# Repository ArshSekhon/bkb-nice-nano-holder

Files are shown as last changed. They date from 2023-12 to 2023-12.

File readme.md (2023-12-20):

## Holder PCB for nice!nano

### nice!nano v2 holder PCB for Bastard Keyboards Charybdis
### WARNING: The PCBs have been validated, they are confirmed to be working, but small changes have been made since the original batch was ordered; there might be discrepancies between the schematic and PCB, use at your own risk and go over the files before ordering any prototypes.

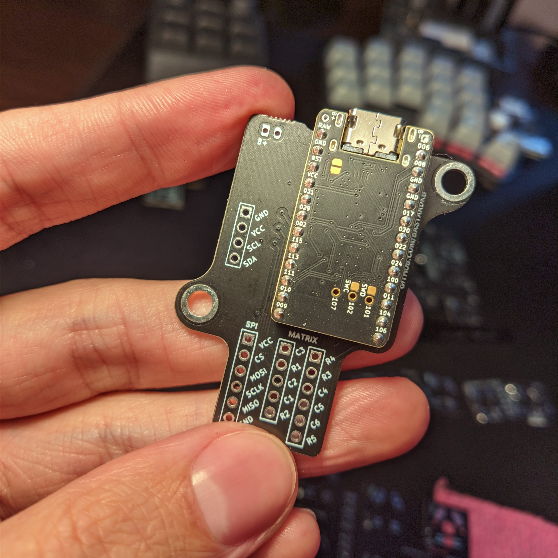
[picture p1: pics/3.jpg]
nice!nano v2 holder


### Features:
- matrix pinout moved to low frequency pins
- spi trackball connection moved to high frequency pins
- removed rgb and serial connection
- repositioned reset footprint
- ph2 battery connector

## Forks

[Holiot carrier](https://github.com/vattern/holiot-carrier) for bluetooth

[Splinktegrated](https://github.com/Bastardkb/Splinktegrated/tree/features/holder2) - Integrated rp2040 and usb-c daughterboard (work in progress)

[Blackpill holder](https://github.com/Bastardkb/adapter-blackpill/)

# License 

This work is licensed under a Creative Commons Attribution-NonCommercial-ShareAlike 4.0 International License.

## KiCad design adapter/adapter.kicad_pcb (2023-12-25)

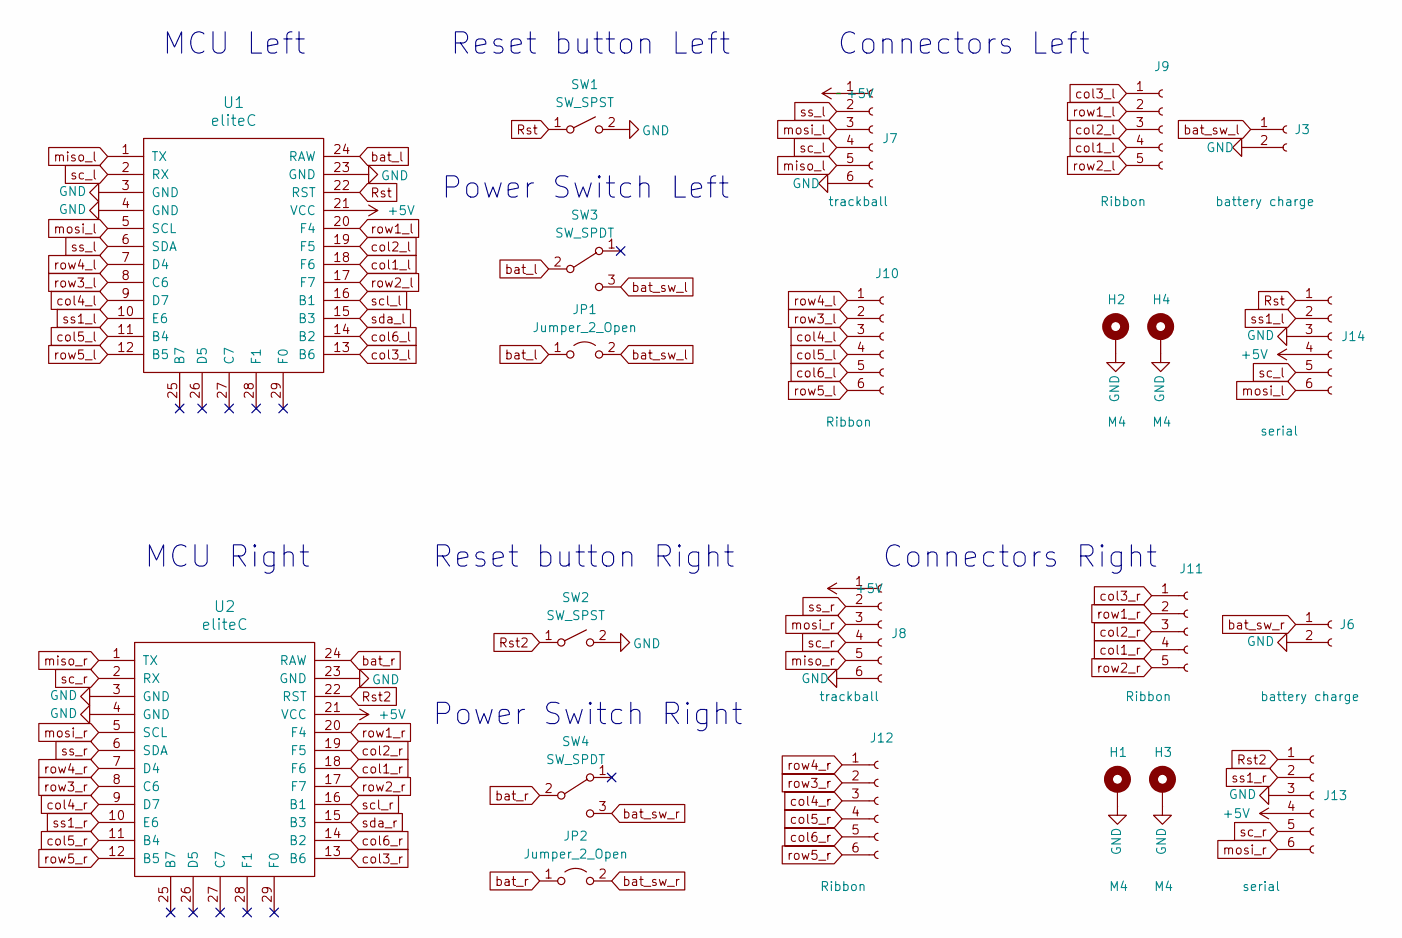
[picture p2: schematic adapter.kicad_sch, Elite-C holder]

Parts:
H1, H2, H3, H4: M4; MountingHole_4mm_Pad_thin
J3, J6: battery charge; JST_PH_B2B-PH-K_1x02_P2.00mm_Vertical
J7, J8: trackball; 6_PinHeader
J9, J11: Ribbon; 5_PinHeader
J10, J12: Ribbon; 6_PinHeader
J13: serial; PinSocket_1x06_P2.54mm_Vertical
J14: serial; PinHeader_1x06_P2.54mm_Vertical
JP1, JP2: Jumper_2_Open; power_switch_jumper
SW1, SW2: SW_SPST; PushSwitch
SW3, SW4: SW_SPDT; SW_SPDT+H-MSK12C01_hor(7pin_SMD)
U1, U2: eliteC; Elite-C

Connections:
+5V: J7.1, J8.1, J13.4, J14.4, U1.21 (VCC), U2.21 (VCC)
GND: H1.1, H2.1, H3.1, H4.1, J3.2, J6.2, J7.6, J8.6, J13.3, J14.3, SW1.2 (B), SW2.2 (B), U1.3 (GND), U1.4 (GND), U1.23 (GND), U2.3 (GND), U2.4 (GND), U2.23 (GND)
Rst: J14.1, SW1.1 (A), U1.22 (RST)
Rst2: J13.1, SW2.1 (A), U2.22 (RST)
bat_l: JP1.1 (A), SW3.2 (B), U1.24 (RAW)
bat_r: JP2.1 (A), SW4.2 (B), U2.24 (RAW)
bat_sw_l: J3.1, JP1.2 (B), SW3.3 (C)
bat_sw_r: J6.1, JP2.2 (B), SW4.3 (C)
col1_l: J9.4, U1.18 (F6)
col1_r: J11.4, U2.18 (F6)
col2_l: J9.3, U1.19 (F5)
col2_r: J11.3, U2.19 (F5)
col3_l: J9.1, U1.13 (B6)
col3_r: J11.1, U2.13 (B6)
col4_l: J10.3, U1.9 (D7)
col4_r: J12.3, U2.9 (D7)
col5_l: J10.4, U1.11 (B4)
col5_r: J12.4, U2.11 (B4)
col6_l: J10.5, U1.14 (B2)
col6_r: J12.5, U2.14 (B2)
miso_l: J7.5, U1.1 (TX)
miso_r: J8.5, U2.1 (TX)
mosi_l: J7.3, J14.6, U1.5 (SCL)
mosi_r: J8.3, J13.6, U2.5 (SCL)
row1_l: J9.2, U1.20 (F4)
row1_r: J11.2, U2.20 (F4)
row2_l: J9.5, U1.17 (F7)
row2_r: J11.5, U2.17 (F7)
row3_l: J10.2, U1.8 (C6)
row3_r: J12.2, U2.8 (C6)
row4_l: J10.1, U1.7 (D4)
row4_r: J12.1, U2.7 (D4)
row5_l: J10.6, U1.12 (B5)
row5_r: J12.6, U2.12 (B5)
sc_l: J7.4, J14.5, U1.2 (RX)
sc_r: J8.4, J13.5, U2.2 (RX)
scl_l: U1.16 (B1)
scl_r: U2.16 (B1)
sda_l: U1.15 (B3)
sda_r: U2.15 (B3)
ss1_l: J14.2, U1.10 (E6)
ss1_r: J13.2, U2.10 (E6)
ss_l: J7.2, U1.6 (SDA)
ss_r: J8.2, U2.6 (SDA)

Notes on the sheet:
Power Switch Right
Reset button Left
Power Switch Left
Connectors Left
Reset button Right
MCU Left
MCU Right
Connectors Right

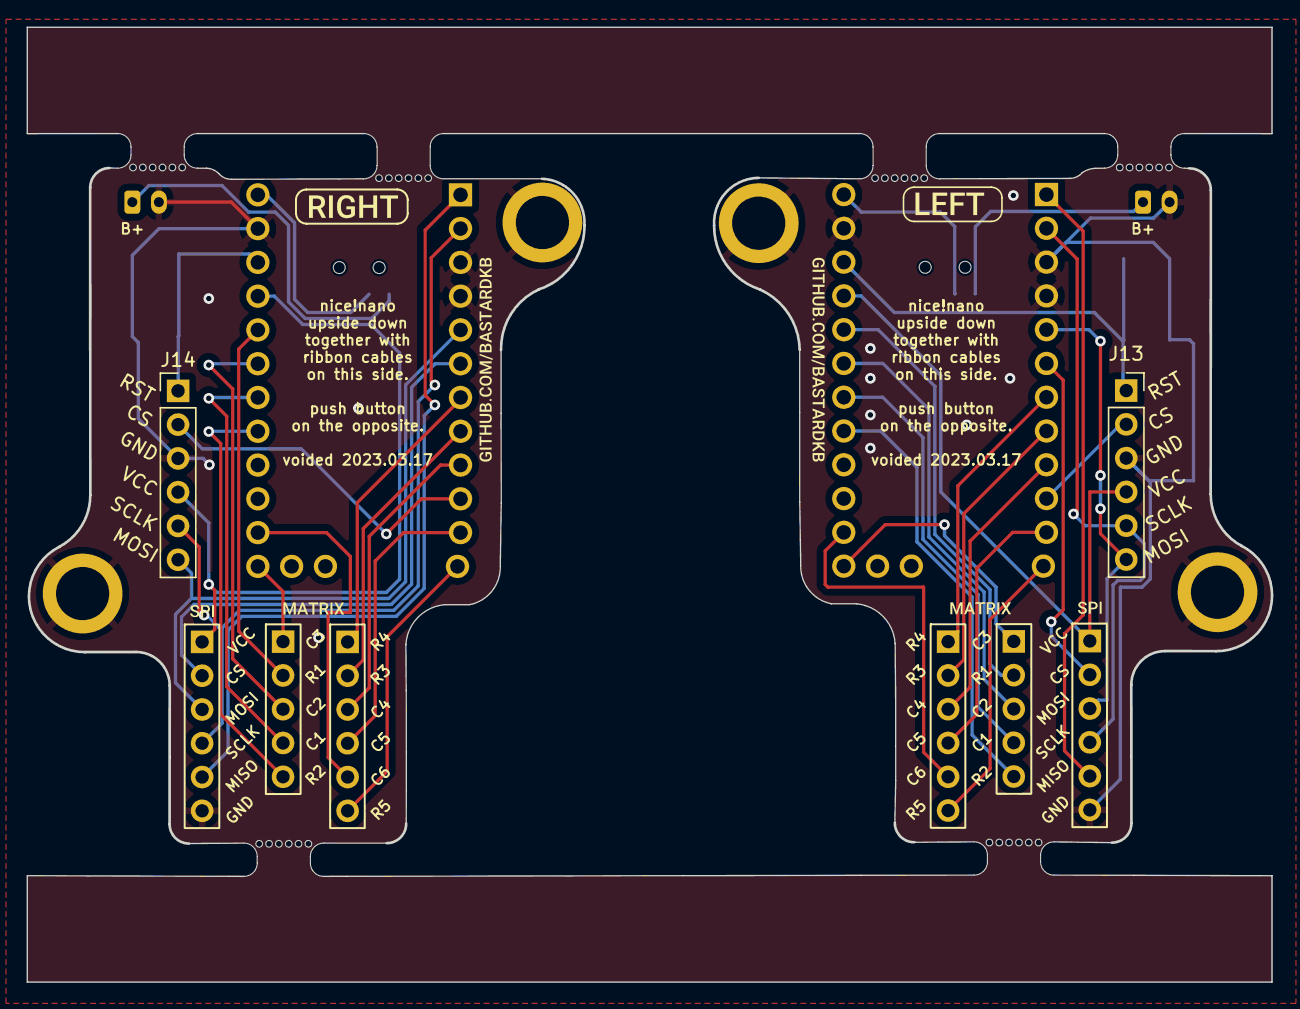
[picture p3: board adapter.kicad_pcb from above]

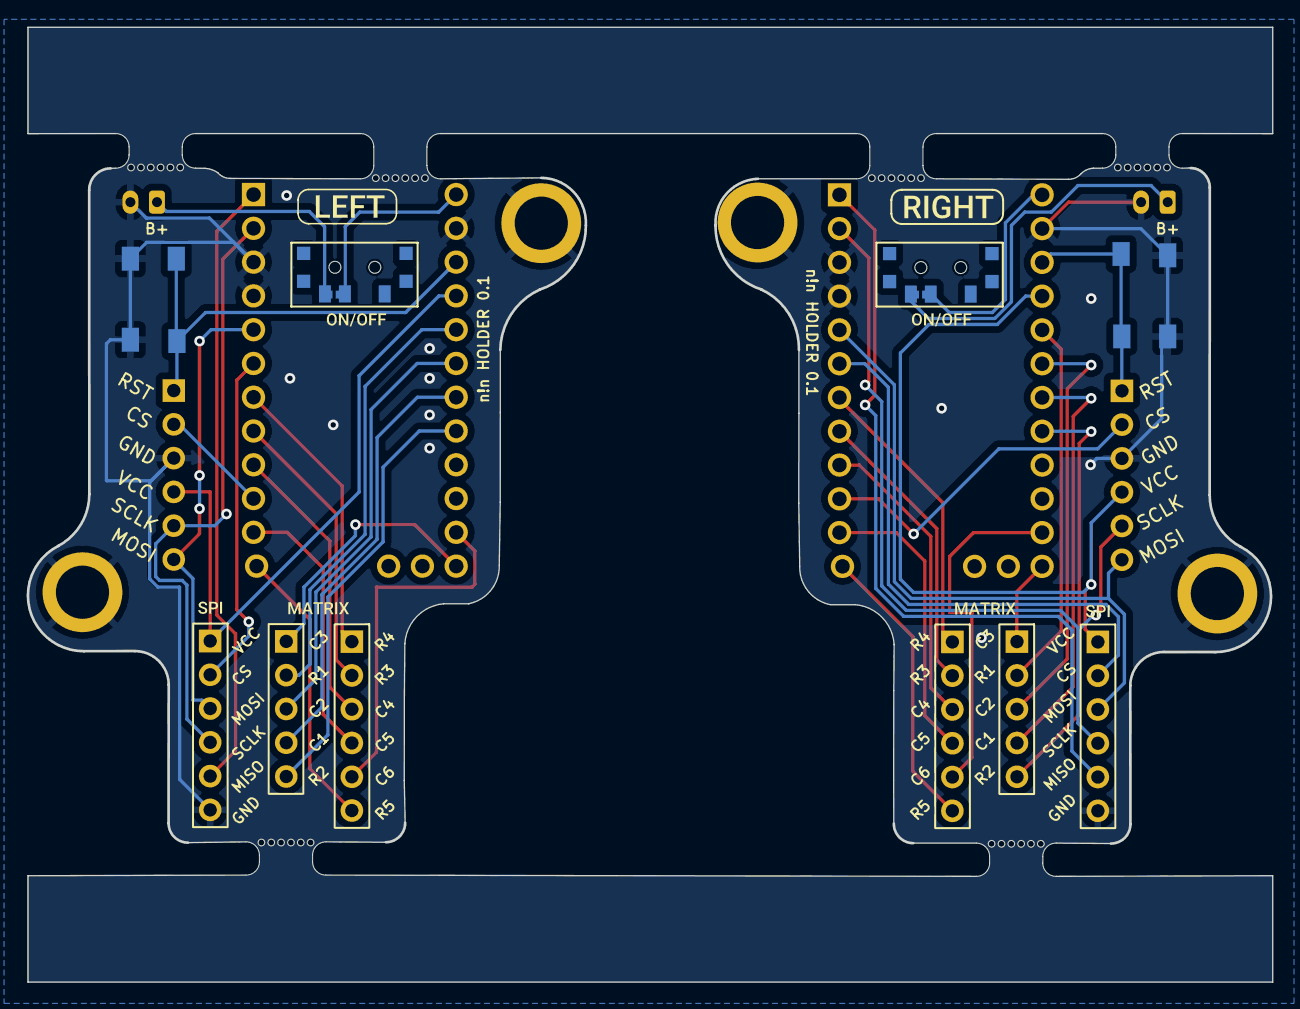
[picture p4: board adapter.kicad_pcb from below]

Board: 2 copper layers, 93.6 x 71.8 mm, 38 parts (16 on the bottom side), 40 nets.

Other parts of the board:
kibuzzard-61F01A92, kibuzzard-61F01A92#2: G***; kibuzzard-61F01A92
kibuzzard-61F01B61, kibuzzard-61F01B61#2: G***; kibuzzard-61F01B61
kibuzzard-61F01940, kibuzzard-61F01940#2, kibuzzard-61F01940#3, kibuzzard-61F01940#4: G***; kibuzzard-61F01940
kibuzzard-61F01957, kibuzzard-61F01957#2, kibuzzard-61F01957#3, kibuzzard-61F01957#4: G***; kibuzzard-61F01957
kibuzzard-620B8593, kibuzzard-620B8593#2: G***; kibuzzard-620B8593
kibuzzard-6208EFFE, kibuzzard-6208EFFE#2: G***; kibuzzard-6208EFFE

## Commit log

2023-12-20 Intial Commit
    [adapter.kicad_pcb, adapter.kicad_sch]
2023-12-25 fixed col6 and gnd fills
    [adapter.kicad_pcb]

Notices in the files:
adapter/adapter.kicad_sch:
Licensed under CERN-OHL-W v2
